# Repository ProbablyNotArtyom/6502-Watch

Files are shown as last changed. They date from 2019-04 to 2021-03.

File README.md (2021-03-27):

# 6502-Watch
6502 powered wearable with an LCD screen, keyboard interface, and compact form factor, all running ehBasic to boot.

<p align="center">
    <a href="https://hackaday.io/project/166496-65p-6502-powered-watch">(Link to this project's Hackaday.io page)</a>
    <br>
    <a href="https://blog.notartyoms-box.net/6502-watch">(Link this project's homepage on my website)</a>
</p>

### About

The 6502 has been around for just about 40 years, yet still powers the hearts of many electrical systems in place today, such as many microcontrollers and embedded systems. In fact, WDC still manufactures the 6502 and 65xx series chips under the 65c02 and 65cxx. I've noticed that WDC also introduced more package variants of the 6502 and 6522, such as PLCC and QFP. Another thing I noticed was the fact that these form factors of the 65c02 are almost never used. Given that the only people buying these are hobbyists, that isn't too suprizing, as they dont offer much over the standard 40 pin DIP.What they do offer, however, is small package size. I went off to try and design the smallest 6502 SBC i could, and was pleasantly suprized with the results. What I ended up with was what i think is the smallest hobbyist 6502 SBC produced. Small enough, in fact, that you could easily wear it on your wrist! I then added the neat little Nokia 5110 LCD and a cool interface, and now have what I believe to be the only 6502-driven watch in existance.

This repository contains all of the KiCad project files for the hardware, and all of the assembly sources for my software. To build the software you will need KickAssembler.

### Hardware

The watch is pretty standard as far as 6502 hardware goes:

 * 65c02 running @ 8MHz
 * 65c22 (controls LCD, keyboard, and buttons)
 * Nokia 5110 LCD (84x48)
 * 32k SRAM
 * 16k ROM
 * C64 Keyboard Connector

Probably the strangest bit there is the full size C64 keyboard connector along the top of the watch. I had wanted to have some form of keyboard input, but most options are entirely out of reach of the poor 6502. The only way i could come up with is to use a preexisting matrix keyboard; I happened to have a lot of unused commodore keyboards, so that's what ended up on there.

The part that ties everything together is really the tiny Nokia LCD. It's interfaced through SPI, which i had to bitbang through the 6522 VIA. The VIA also interfaces with the keyboard, and the face buttons. An interesting thing to note here is that the VIA only has 16 i/o pins, which in this case are all needed to interface just with the keyboard alone. I was able to use some of those pins for both the keyboard and the LCD without causing any sort of corruption with a bit of luck, and a lot more trial and error.

### Software

The watch has a few different things on its ROM. The primary thing is G'Mon, a machine monitor i wrote for the 6502. It  supports viewing memory in single and batch, depositing memory in single or batch, jumping to programs, filling blocks of memory with a pattern byte, and moving blocks of memory. I had to strip a few of the less useful commands out in order to fit it on the ROM with everything else. The secondary thing on there is Lee Davidson's Enhanced Basic. I was just barely able to fit into the ROM with everything else, like there are only around 100 bytes free. EhBasic has been modified to hook into the watch's main code, but other than that it's a completely normal version of EhBasic!

The thing that greets you when you start up the watch is the watch interface. Clever name, i know. It just provides a graphical menu you can move through to select what you want to run. This is the only place where the face buttons are actually used, at least on purpose. The topmost button is what brings up the menu. Interesting bit about that: its connected directly to the NMI pin on the 6502, so it can be used to get back to the watch menu from almost anywhere on the thing (unless you crash the 6502).

In my sources, there is a big blob of code that handles interfacing with the watch hardware; It's called the kernel there, but its less of a kernel and more of a library everything else references. Some of the more interesting things in there are the SPI bitbanging stuff for the LCD, and the matrix scanning and decoding routine for the keyboard.

Speaking of sources, they are all uploaded on here, of course. All the assembler code is written to be assembled using KickAssembler, and makes quite heavy use of its macro capabilities, so i doubt it would be fun to try and assemble with anything else. Here i have also included the EhBasic sources that i have modified; They have been modified to be assembled with KickAssembler. Everything builds at the same time, just run the ./Compile.sh script and it will spit out a ROM image. If for some reason you feel the need to fiddle with it, then make sure to go to Configuration.asm: That's the header that holds a bunch of the miscellaneous variables, like the location of the ROM in memory.

If you every wanted to run the software yourself, then you can do that as well. If you set the Emulated variable in the config file to true, then it will build a ROM for use with Symon.

### Other Software Toys

I have written a few extra programs to show what the hardware itself can do. The first thing is a little sprite demo that has 8 animated software sprites bouncing around the screen, plus a text scroller along the top. The visibility is quite poor with it, as the LCD sure does take its time with updating the pixels, which causes everything moving to be a little blurry. To combat this I had to wait a bit after each frame for the LCD to update, which means that the demo itself runs a little slower than it actually could on the hardware. A video of this demo in action is in the Demos section.

Did i mention it runs Tetris? Because yea, it sure does. I wrote a version of Tetris for the watch not long after realizing it was probably the only practical thing that it could feasibly do. Its a pretty standard Tetris clone, following pretty much all of the mechanics of the original versions. This means having the scoring system, having the progressive levels, all the tetrominoes, etc. Its controlled using the face buttons, using the navigation buttons as left & right, the center button as rotate, and the NMI button as the drop button. At the moment I don't have actual recordings of Tetris running on the watch, mostly because i am too lazy to do that much work for a project that was finished nearly 2 and a half years as of this write-up, but i do have the graphics assets i made for it, and have put them together into what it looks like while. If you don't believe that I wrote Tetris for it, then don't worry, just take a look at the sources that i have included with the project's main downloads.

### More Information

 * [My Website](http://notartyoms-box.net/6502watch.html)

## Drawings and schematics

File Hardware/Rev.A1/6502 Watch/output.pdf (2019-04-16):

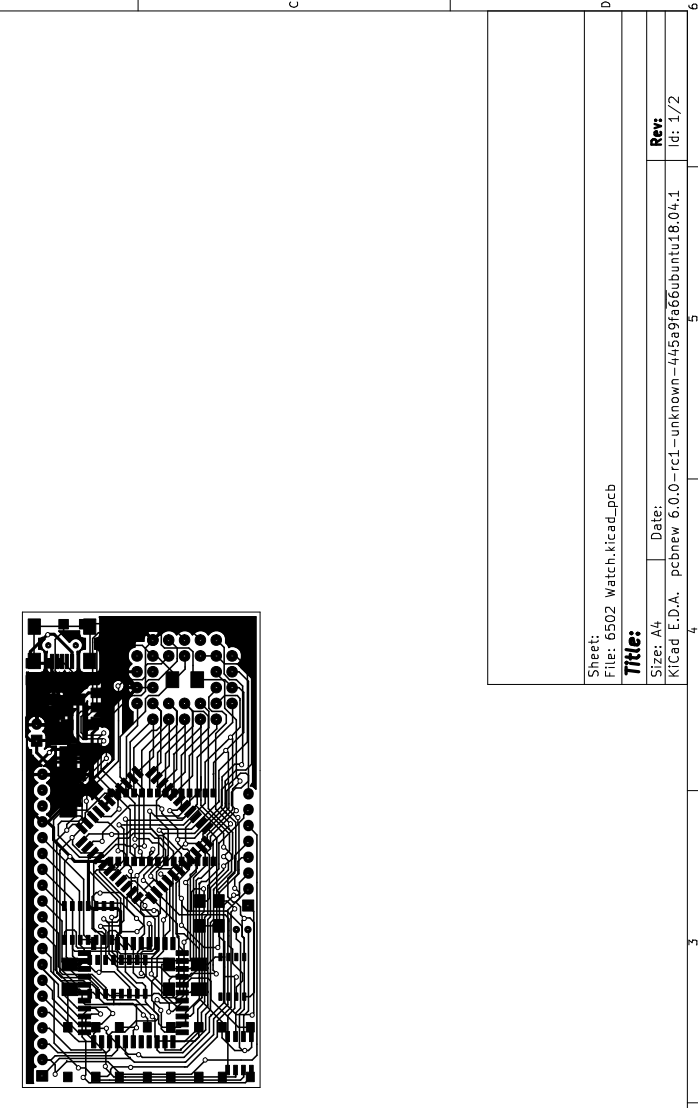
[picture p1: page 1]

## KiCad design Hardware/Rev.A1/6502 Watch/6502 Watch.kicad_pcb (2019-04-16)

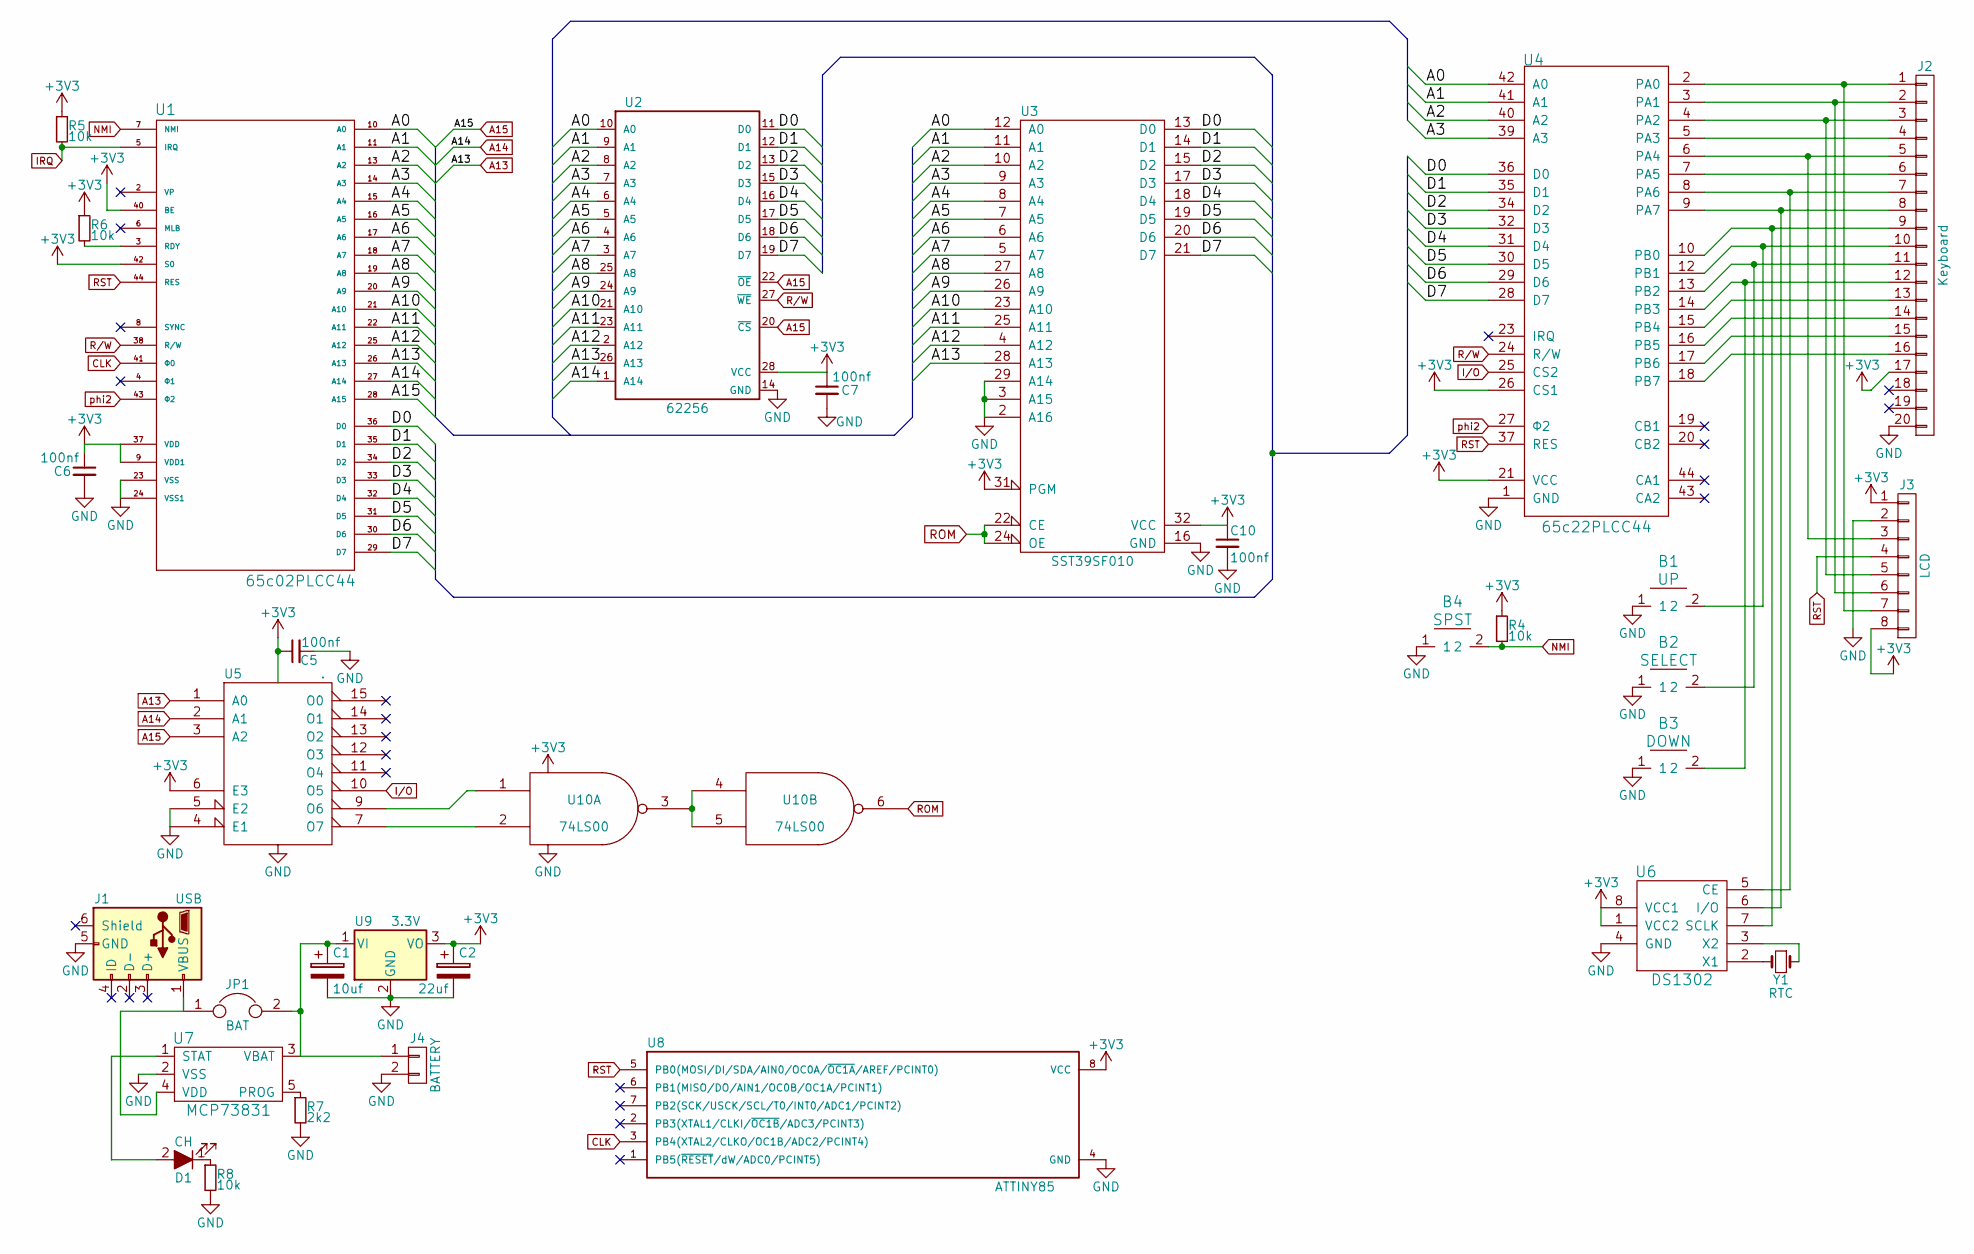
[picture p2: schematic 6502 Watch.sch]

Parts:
B1: UP; SW_SPST_B3S-1000(4P)
B2: SELECT; SW_SPST_B3S-1000(4P)
B3: DOWN; SW_SPST_B3S-1000(4P)
B4: SPST; SW_SPST_B3S-1000(4P)
C1: 10uf; C_1206_HandSoldering
C2: 22uf; C_1206_HandSoldering
C5, C6, C7, C10: 100nf; C_1210_HandSoldering
D1: CH; LED_1206
J1: USB; USB_Mini-B
J2: Keyboard; Pin_Header_Angled_1x20_Pitch2.54mm
J3: LCD; Pin_Header_Straight_1x08_Pitch2.54mm
J4: BATTERY; Pin_Header_Straight_1x02_Pitch2.54mm
JP1: BAT; R_0805_HandSoldering
R4, R5, R6, R8: 10k; R_1206_HandSoldering
R7: 2k2; R_1206_HandSoldering
U1: 65c02PLCC44; PLCC-44
U2: 62256; SOP-28_8.40x48mm_Pitch1.27mm
U3: SST39SF010; PLCC-32_THT-Socket_Fixed
U4: 65c22PLCC44; PLCC-44
U5: .; SOIC-16_3.9x9.9mm_Pitch1.27mm
U6: DS1302; SOIC-8_3.9x4.9mm_Pitch1.27mm
U7: MCP73831; SOT-23-5_HandSoldering
U8: ATTINY85; SOIC-8-N
U9: 3.3V; SOT-223-3Lead_TabPin2
U10: 74LS00; SOIC-14_3.9x8.7mm_Pitch1.27mm
Y1: RTC; Crystal_DS26_d2.0mm_l6.0mm_Horizontal

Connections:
+3V3: C2.1, C5.1, C6.1, C7.1, C10.1, J2.17, J3.1, J3.8, R4.1, R5.1, R6.1, U1.9 (VDD1), U1.37 (VDD), U1.40 (BE), U1.42 (S0), U2.28 (VCC), U3.31 (PGM), U3.32 (VCC), U4.21 (VCC), U4.26 (CS1), U5.6 (E3), U5.16 (VCC), U6.1 (VCC2), U6.8 (VCC1), U8.8 (VCC), U9.3 (VO), U10.14 (VCC)
/A0: U1.10 (A0), U2.10 (A0), U3.12 (A0), U4.42 (A0)
/A1: U1.11 (A1), U2.9 (A1), U3.11 (A1), U4.41 (A1)
/A2: U1.13 (A2), U2.8 (A2), U3.10 (A2), U4.40 (A2)
/A3: U1.14 (A3), U2.7 (A3), U3.9 (A3), U4.39 (A3)
/A4: U1.15 (A4), U2.6 (A4), U3.8 (A4)
/A5: U1.16 (A5), U2.5 (A5), U3.7 (A5)
/A6: U1.17 (A6), U2.4 (A6), U3.6 (A6)
/A7: U1.18 (A7), U2.3 (A7), U3.5 (A7)
/A8: U1.19 (A8), U2.25 (A8), U3.27 (A8)
/A9: U1.20 (A9), U2.24 (A9), U3.26 (A9)
/A10: U1.21 (A10), U2.21 (A10), U3.23 (A10)
/A11: U1.22 (A11), U2.23 (A11), U3.25 (A11)
/A12: U1.25 (A12), U2.2 (A12), U3.4 (A12)
/D0: U1.36 (D0), U2.11 (D0), U3.13 (D0), U4.36 (D0)
/D1: U1.35 (D1), U2.12 (D1), U3.14 (D1), U4.35 (D1)
/D2: U1.34 (D2), U2.13 (D2), U3.15 (D2), U4.34 (D2)
/D3: U1.33 (D3), U2.15 (D3), U3.17 (D3), U4.32 (D3)
/D4: U1.32 (D4), U2.16 (D4), U3.18 (D4), U4.31 (D4)
/D5: U1.31 (D5), U2.17 (D5), U3.19 (D5), U4.30 (D5)
/D6: U1.30 (D6), U2.18 (D6), U3.20 (D6), U4.29 (D6)
/D7: U1.29 (D7), U2.19 (D7), U3.21 (D7), U4.28 (D7)
A13: U1.26 (A13), U2.26 (A13), U3.28 (A13), U5.1 (A0)
A14: U1.27 (A14), U2.1 (A14), U5.2 (A1)
A15: U1.28 (A15), U2.20 (~CS), U2.22 (~OE), U5.3 (A2)
CLK: U1.41 (Φ0), U8.3 (PB4(XTAL2/CLKO/OC1B/ADC2/PCINT4))
GND: B1.1, B2.1, B3.1, B4.1, C1.2, C2.2, C5.2, C6.2, C7.2, C10.2, J1.5 (GND), J2.20, J3.2, J4.2, R7.2, R8.2, U1.23 (VSS), U1.24 (VSS1), U2.14 (GND), U3.2 (A16), U3.3 (A15), U3.16 (GND), U3.29 (A14), U4.1 (GND), U5.4 (E1), U5.5 (E2), U5.8 (GND), U6.4 (GND), U7.2 (VSS), U8.4 (GND), U9.2 (GND), U10.7 (GND)
I/O: U4.25 (CS2), U5.10 (O5)
IRQ: R5.2, U1.5 (IRQ)
NMI: B4.2, B4.4, R4.2, U1.7 (NMI)
unnamed: B1.2, J2.10, U4.12 (PB1)
unnamed: B2.2, J2.11, U4.13 (PB2)
unnamed: B3.2, J2.12, U4.14 (PB3)
unnamed: C1.1, J4.1, JP1.2, U7.3 (VBAT), U9.1 (VI)
unnamed: D1.1 (K), R8.1
unnamed: D1.2 (A), U7.1 (STAT)
unnamed: J1.1 (VBUS), JP1.1, U7.4 (VDD)
unnamed: J2.1, J3.7, U4.2 (PA0)
unnamed: J2.2, J3.6, U4.3 (PA1)
unnamed: J2.3, J3.5, U4.4 (PA2)
unnamed: J2.4, U4.5 (PA3)
unnamed: J2.5, J3.3, U4.6 (PA4)
unnamed: J2.6, U4.7 (PA5)
unnamed: J2.7, U4.8 (PA6), U6.5 (CE)
unnamed: J2.8, U4.9 (PA7), U6.6 (I/O)
unnamed: J2.9, U4.10 (PB0), U6.7 (SCLK)
unnamed: J2.13, U4.15 (PB4)
unnamed: J2.14, U4.16 (PB5)
unnamed: J2.15, U4.17 (PB6)
unnamed: J2.16, U4.18 (PB7)
unnamed: R6.2, U1.3 (RDY)
unnamed: R7.1, U7.5 (PROG)
unnamed: U6.2 (X1), Y1.2
unnamed: U6.3 (X2), Y1.1
unnamed: U5.9 (O6), U10.1
unnamed: U5.7 (O7), U10.2
unnamed: U10.3, U10.4, U10.5
R/W: U1.38 (R/W), U2.27 (~WE), U4.24 (R/W)
ROM: U3.22 (CE), U3.24 (OE), U10.6
RST: J3.4, U1.44 (RES), U4.37 (RES), U8.5 (PB0(MOSI/DI/SDA/AIN0/OC0A/~OC1A~/AREF/P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)
phi2: U1.43 (Φ2), U4.27 (Φ2)

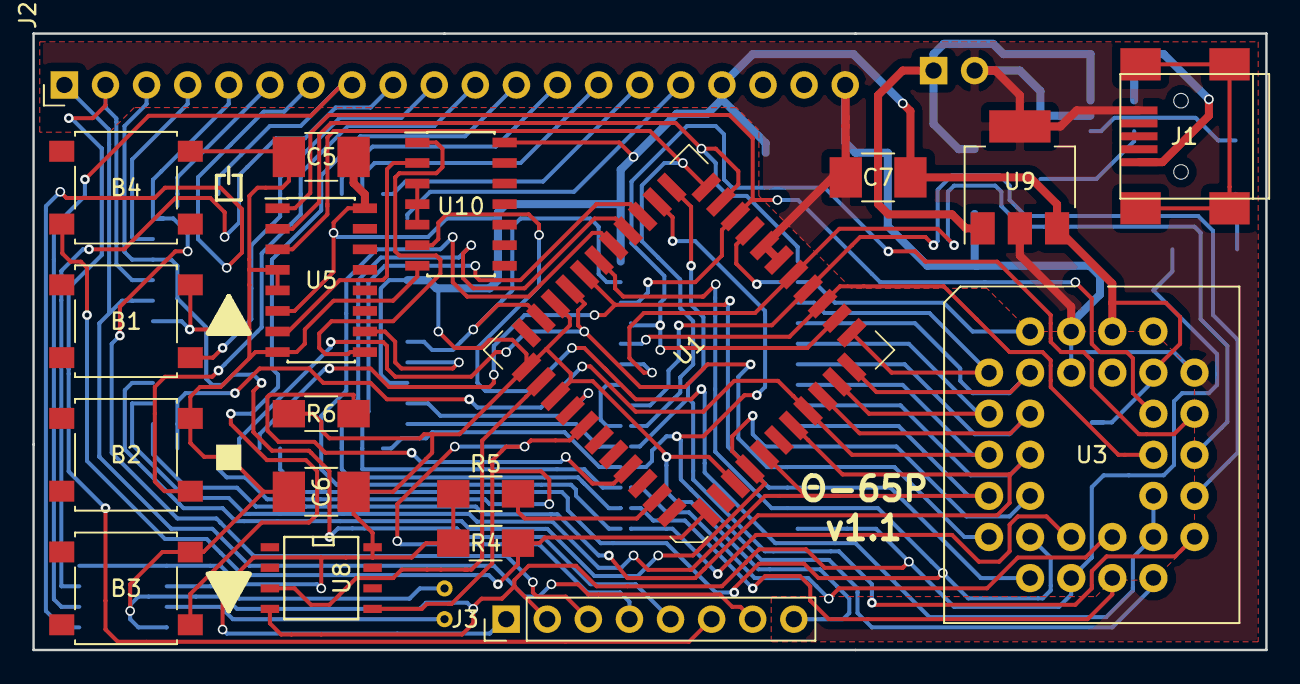
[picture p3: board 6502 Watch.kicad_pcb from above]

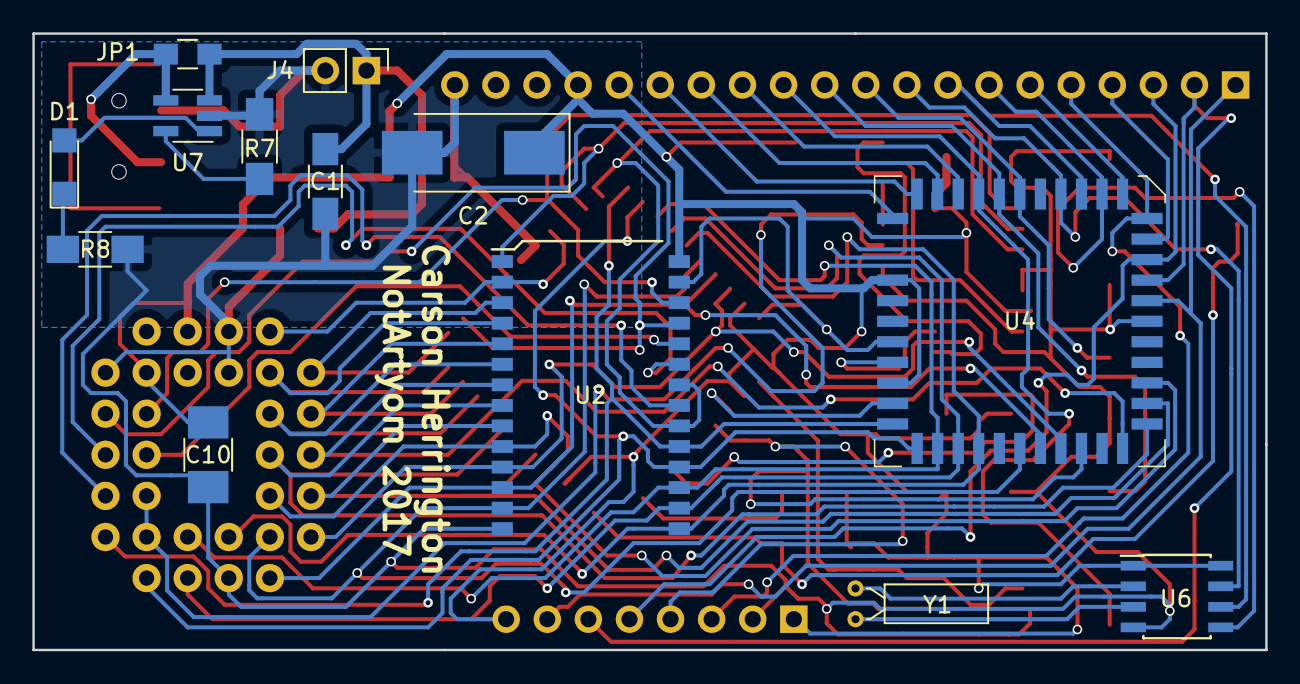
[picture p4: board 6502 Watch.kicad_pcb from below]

Board: 2 copper layers, 76.2 x 38.1 mm, 32 parts (13 on the bottom side), 61 nets.

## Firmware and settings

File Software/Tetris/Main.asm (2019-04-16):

//------------------Origin------------------
				
			*=$C000				// For use with Symon
KStart:
//-----------------Imports------------------	

			#import "Variables.asm"

//------------------Start-------------------	

INIT:							// RAM test, I/O init																																												
			sei					// Disable IRQ
			cld					// Clear decimal flag
			ldx #$FF			// Load X with stack pointer
			txs					// Init stack pointer
			cld
			lda #$00
			sta ADDRS
			sta Score			// Reset game vaiables
			sta ScoreH
			sta ScoreHH
			sta Lines
			lda #$02
			sta ADDRSHI
			jsr RAMInit
			jsr LCDInit
			jsr RNDInit
			lda #$FF
			sta DropLVL
			lda #$0D
			sta BlockID_Next
			
			lda #<Collision		// Write the collision table to memory
			sta GTmp5
			lda #>Collision
			sta GTmp6
			lda #<Table			
			sta GTmp3
			lda #>Table
			sta GTmp4
			ldy #$FF
			ldx #$00
Pct:		iny
			lda (GTmp3),y		// Load a byte of the bitmap
			sta (GTmp5),y
			cpx #$01			// If X != 1
			bne !+
			cpy #$30			// If Y
			bne Pct
			jmp INe			
!:			cpy #$FF			
			bne Pct				
			inc GTmp4			// Increase the High byte of the index		
			inc GTmp6		
			ldx #$01			// Set X == 1 so the second routine can start
			jmp Pct		
INe:
		.if (Emulated){	
			jmp Main	
		}		
			lda #<Title
			sta GTmp3
			lda #>Title
			sta GTmp4
			jsr WriteBMP
			
M0:			lda #$FF
			sta DDRB
			sta PORTB
			lda #$00
			sta DDRB			
			lda PORTB
			ora #%11110001
			cmp #SW_SELECT
			bne M0
Main:			
			lda #<Game
			sta GTmp3
			lda #>Game
			sta GTmp4
			jsr WriteBMP
			
			lda #$01
			sta Level
			
			jsr BlockNew
!:			jsr BDelay
			jsr BlockDown
			jmp !-
					 		
//----------------Functions-----------------	

RAMInit:														
			ldx #$00													
Ra1:		lda	#$00
			sta (ADDRS,x)		// Store byte
						
			lda ADDRS			// Load accumulator with low byte of current test address
			cmp #$FF			// Compare with #$FF to see if it is time to cycle the high byte
			bne !+				// if A =/= #$FF goto end. else continue
			inc ADDRSHI			// Increase current test address high byte
!:			inc ADDRS			// Store #$00 in the low byte				
		
			lda ADDRSHI			// Compare High byte of current address to 80
			cmp #80
			bne Ra1																										
			rts	
			
LCDInit:              
			pha          
			lda DDRA								
			ora #%00011111		// Set the VIA bits to be outputs								
			sta DDRA          
            lda PORTA
            and #%11110110		// Set CLK and RES low
            sta PORTA
            nop					// Delay for a bit
            nop
			lda PORTA
			ora #$00001000		// Set RES high
			sta PORTA
			nop					// Delay a little bit more
			nop
			
			lda #%00100001		// Function set, H == 1
			jsr Command
			lda #%11000111		// Set Contrast
			jsr Command
			lda #%00100000		// Function set, H == 0
			jsr Command
			lda #%00001100		// Set Display Config
			jsr Command
			lda #%10000000		// Set X = 0
			jsr Command
			lda #%01000000		// Set Y = 0
			jsr Command			
			
			jsr LCDClear		// Clear the LCD
			pla
			rts					// Return

LCDHome:
			pha
			jsr LCDClear
			lda #%00100000		// Function set, H == 0
			jsr Command
			lda #%10000000		// Set X = 0
			jsr Command
			lda #%01000000		// Set Y = 0
			jsr Command
			pla
			rts

LCDClear:
			pha
			txa
			pha
			tya
			pha
			ldy #$00
			ldx #$00
			lda #%10000000		// Set X = 0
			jsr Command
			lda #%01000000		// Set Y = 0
			jsr Command
CL1:		lda #$00
			jsr WriteBYTE		// Write the byte
			iny					// Increase the index
			cpx #$01			// Check if we're on the second loop
			beq !+
			cpy #$FF			
			bne CL1					
			ldx #$01			// Set X == 1 so the second routine can start
			jmp CL1				// Jump back to the loop
!:			cpy #$F8			
			bne CL1
			
			pla			
			tay			
			pla			
			tax			
			pla				
			rts			
						
Command:
			sta GTmp			// Save input				
			tya					// Push y to the stack	
			pha																				
			lda DDRA								
			ora #%00011111		// Set the VIA bits to be outputs								
			sta DDRA							
			lda #%00111000		// Set LCD_RS bit to character input mode (High)						
			sta PORTA			// Output it							
!:			lda PORTA
			and #%11101111		// Set the enable bit low
			sta PORTA			// Output it
			ldy #$FF			// Setup Y for the output loop													
!:			lda PORTA			
			and #%11111101		// Set the Data line low to ready it for bit-shifting 
			sta PORTA			// Output it
			lda #$00			// Load A with zero for input
			clc					// Clear Carry
			asl GTmp			// Shift next bit of The input into Carry	
			rol					// Rol the bit into A
			clc					// Clear carry to make sure bit 0 of A == 0
			rol					// Rol A to put the data bit in the correct location
			ora PORTA			// Or it with the output
			sta PORTA			// Output the data bit
			inc	PORTA			// Pulse the Clock to latch the data
			dec	PORTA					
			iny 				// Increase the index
			cpy #$08			// If Y == 8, then all of the bits have been output
			bne !-				// If not, then jmp to output another bit				
!:			
			lda #%00111000
			sta PORTA
			pla								
			tay					// Pull Y from the stack			
			rts					// Return									
												
WriteBYTE: 													
			sta GTmp			// Save input				
			pha		
			tya					// Push y to the stack	
			pha											
			lda DDRA								
			ora #%00011111		// Set the VIA bits to be outputs								
			sta DDRA							
			lda #%00111100		// Set LCD_RS bit to character input mode (High)						
			sta PORTA			// Output it							
!:			lda PORTA
			and #%11101111		// Set the enable bit low
			sta PORTA			// Output it
			ldy #$FF			// Setup Y for the output loop													
!:			lda PORTA			
			and #%11111101		// Set the Data line low to ready it for bit-shifting 
			sta PORTA			// Output it
			lda #$00			// Load A with zero for input
			clc					// Clear Carry
			asl GTmp			// Shift next bit of The input into Carry	
			rol					// Rol the bit into A
			clc					// Clear carry to make sure bit 0 of A == 0
			rol					// Rol A to put the data bit in the correct location
			ora PORTA			// Or it with the output
			sta PORTA			// Output the data bit
			inc	PORTA			// Pulse the Clock to latch the data
			dec	PORTA					
			iny 				// Increase the index
			cpy #$08			// If Y == 8, then all of the bits have been output
			bne !-				// If not, then jmp to output another bit				
!:			
			lda #%00111000
			sta PORTA
			pla								
			tay					// Pull Y from the stack			
			pla		
			rts					// Return									
												
WriteBMP:						// Writes a bitmap to the screen. GTmp3(L) and GTmp4(H) must contain a pointer to the bitmap
			pha
			txa
			pha
			tya
			pha
			jsr LCDHome
			lda #<Screen
			sta GTmp5
			lda #>Screen
			sta GTmp6
			ldy #$FF
			ldx #$00
WB1:		iny
			lda (GTmp3),y		// Load a byte of the bitmap
			sta (GTmp5),y
			jsr WriteBYTE		// Write the byte
			cpx #$01			// If X != 1
			bne !+
			cpy #$F8			// If Y
			bne WB1
			pla			
			tay			
			pla			
			tax			
			pla				
			rts
			
!:			cpy #$FF			
			bne WB1				
			inc GTmp4			// Increase the High byte of the index		
			inc GTmp6		
			ldx #$01			// Set X == 1 so the second routine can start
			jmp WB1				// Jump back to the loop								
												
SETCursor:
			pha
			lda LCDX								
			ora #%10000000								
			jsr Command								
			lda LCDY					
			asl					
			asl					
			asl					
			ora #%01000000								
			jsr Command							
			pla							
			rts							
										
SETCursor_3b:
			pha
			lda LCDX								
			ora #%10000000								
			jsr Command								
			lda LCDY									
			ora #%01000000								
			jsr Command							
			pla							
			rts							
												
BDelay:							// Dealy for a lot of cycles
			txa
			pha
			tya 
			pha
			
			ldx DropDelay		// Load X with #$FF
RS:			ldy #$FF			// Load Y with #$FF
!:			dey					// Decrease Y (Sub loop)
		.if (Emulated){
			rol $10
		}else{
			rol $10
			ror $10
			rol $10
			ror $10
			rol $10
			ror $10
			rol $10
			ror $10
			rol $10
			ror $10
			rol $10
			ror $10
		}
			cpy #$00			// Compare it to 0
			bne !-				// If Y =/= 0, loop again
			jsr Input
			dex					// After one full loop of Y, Decrease X by one
			cpx #$00			// Compare X to 0
			bne RS				// If X =/= 0, loop Y once more			
			pla 
			tay
			pla
			tax
			rts												

Input:		
			pha
			txa
			pha
!:			lda #$FF
			sta DDRB
			sta PORTB
			lda #$00
			sta DDRB			
			lda PORTB
			ora #%11110001
			cmp #$FF
			beq !+
			cmp lastkey
			bne !+
			jmp IOe
!:			sta lastkey
			cmp #SW_SELECT
			bne !+
			jsr BlockRotate
			jmp IOe
			
!:			cmp #SW_LEFT
			bne !+
			jsr BlockLeft
			jmp IOe
			
!:			cmp #SW_RIGHT
			bne !+
			jsr BlockRight
			jmp IOe
IOe:			
!:			pla
			tax
			pla
			rts

//-------------Game Functions---------------					

GameEnd:
			jmp INIT
CHLines:
			lda Lines
			cmp #$0A
			bne !+
			inc Level		
			lda #$00		
			sta Lines		
!:			rts

CHLevel:
			ldy Level
			lda LDTbl,y
			sta DropLVL
			rts
			
PRScore:						
			pha				
			tya				
			pha				

			lda #$05								
			sta TLength								
			lda #<Tiles+150
			sta B0Tiles
			lda #$F7							
			sta B0TilesH										
			lda #13
			sta LCDX										
													
			lda ScoreHH			
			and #%00001111			
			tay			
			lda NTblL,y
			sta BTiles
			lda NTblH,y
			sta BTilesH		
			lda #12
			sta LCDY	
			jsr PBlock_CL											
													
			lda ScoreH				
			and #%11110000				
			lsr				
			lsr				
			lsr				
			lsr				
			tay
			lda NTblL,y
			sta BTiles
			lda NTblH,y
			sta BTilesH
			lda #08
			sta LCDY
			jsr PBlock_CL			
			lda ScoreH			
			and #%00001111			
			tay			
			lda NTblL,y
			sta BTiles
			lda NTblH,y
			sta BTilesH		
			lda #12
			sta LCDY	
			jsr PBlock_CL			
						
			lda Score				
			and #%11110000				
			lsr				
			lsr				
			lsr				
			lsr				
			tay
			lda NTblL,y
			sta BTiles
			lda NTblH,y
			sta BTilesH
			lda #16
			sta LCDY
			jsr PBlock_CL			
			lda Score		
			and #%00001111			
			tay			
			lda NTblL,y
			sta BTiles
			lda NTblH,y
			sta BTilesH		
			lda #20
			sta LCDY
			jsr PBlock_CL			
	
			pla				
			tay				
			pla				
			rts				
									
PRLevel:
			pha				
			tya				
			pha				

			lda #$05								
			sta TLength								
			lda #<Tiles+150
			sta B0Tiles
			lda #$F7							
			sta B0TilesH										
			lda #01
			sta LCDX													
						
			lda Level				
			and #%11110000				
			lsr				
			lsr				
			lsr				
			lsr				
			tay
			lda NTblL,y
			sta BTiles
			lda NTblH,y
			sta BTilesH
			lda #16
			sta LCDY
			jsr PBlock_CL			
			lda Level		
			and #%00001111			
			tay			
			lda NTblL,y
			sta BTiles
			lda NTblH,y
			sta BTilesH		
			lda #20
			sta LCDY
			jsr PBlock_CL			
	
			pla				
			tay				
			pla				
			rts		
			
BlockSlam:
			pha
			lda #$01
			sta DropDelay
			pla
			rti 
			
BlockErase:						// Erases a tetromino		
			pha			
			tya			
			pha			
			txa			
			pha			
									
			ldy BlockID
			lda TTblL,y			// Get the low byte of the block's graphics pointer
			sta BTiles
			lda TTblH,y			// Get the high byte of the block's graphics pointer
			sta BTilesH
			lda TETblL,y		// Get the low byte of the block's graphics pointer
			sta B0Tiles
			lda TETblH,y		// Get the high byte of the block's graphics pointer
			sta B0TilesH			
						
			ldy BlockX
			lda BSTblX,y		// Use the Block X position to find the Y screen position of the block
			sta LCDY
			ldy BlockY
			lda BSTblY,y		// Use the Block Y position to find the X screen position of the block
			sta LCDX
			jsr EBlock		
						
			pla			
			tax			
			pla			
			tay			
			pla			
			rts			
						
BlockPrint:						// Prints a block at the current (BlockX, BlockY) position			
			pha			
			tya			
			pha			
			txa			
			pha			
						
			ldy BlockID
			lda TTblL,y			// Get the low byte of the block's graphics pointer
			sta BTiles
			lda TTblH,y			// Get the high byte of the block's graphics pointer
			sta BTilesH
			lda TETblL,y		// Get the low byte of the block's graphics pointer
			sta B0Tiles
			lda TETblH,y		// Get the high byte of the block's graphics pointer
			sta B0TilesH			
						
			ldy BlockX
			lda BSTblX,y		// Use the Block X position to find the Y screen position of the block
			sta LCDY
			ldy BlockY
			lda BSTblY,y		// Use the Block Y position to find the X screen position of the block
			sta LCDX
			jsr PBlock	
			
			pla			
			tax			
			pla			
			tay			
			pla			
			rts			
							
BlockRight:						// Moves the tetromino right one space
			jsr ECData
			inc BlockX
			jsr CCData
			bcs !+
			dec BlockX
			jsr BlockErase
			inc BlockX
			jsr PCData
			jsr BlockPrint
			rts
!:			dec BlockX
			jsr PCData
			rts					

BlockLeft:						// Moves the tetromino left one space
			jsr ECData
			dec BlockX
			jsr CCData
			bcs !+
			inc BlockX
			jsr BlockErase
			dec BlockX
			jsr PCData
			jsr BlockPrint
			rts
!:			inc BlockX
			jsr PCData
			rts

BlockDown:						// Moves the tetromino down one space
			pha					
			jsr ECData		
			dec BlockY
			jsr CCData
			bcs !+
			inc BlockY
			jsr BlockErase
			dec BlockY
			jsr PCData
			jsr BlockPrint
			pla
			rts			
!:			inc BlockY
			jsr PCData
			jsr BlockNew
			pla
			rts
			
BlockRotate:					// Rotates a block CW
			pha
			tya
			pha
			
			jsr ECData
			ldy BlockID
			lda RTbl,y			// Lookup how many rotations are left in this blocks cycle
			cmp #$00
			bne R0				// If there are still cycles left, then branch to continue
			lda BlockID
			pha
			lda BlockID_B
			sta BlockID
			jsr CCData
			bcs !+
			pla
			sta BlockID
			jsr BlockErase
			lda BlockID_B
			sta BlockID
			jsr PCData
			jsr BlockPrint
			jmp Re
!:			pla
			sta BlockID
			jsr PCData
			jmp Re				// Exit the routine
R0:			inc BlockID
			jsr CCData
			bcs !+
			dec BlockID
			jsr BlockErase
			inc BlockID
			jsr PCData
			jsr BlockPrint
			jmp Re
!:			dec BlockID
			jsr PCData
			jmp Re
			
Re:			pla
			tay
			pla
			rts

BlockNew:						// Creates a new tetromino and sets up it's graphics data
			pha
			tya
			pha
			
			jsr CLine			// Check if any lines have been formed
			
			lda #%10000000		// Set X = 0
			jsr Command
			lda #%01000000		// Set Y = 0
			jsr Command
			lda #$03
			jsr WriteBYTE
			
			lda BlockID_Next
			pha
			jsr IDGen
			tay
			lda BTbl,y			// Use the random number as an index to get the next blockID
			sta BlockID_Next
			pla
			sta BlockID
			sta BlockID_B
			lda #07
			sta LCDX
			lda #31
			sta LCDY
			
			ldy BlockID
			lda TTblL,y			// Get the low byte of the block's graphics pointer
			sta BTiles
			lda TTblH,y			// Get the high byte of the block's graphics pointer
			sta BTilesH
			lda TETblL,y		// Get the low byte of the block's graphics pointer
			sta B0Tiles
			lda TETblH,y		// Get the high byte of the block's graphics pointer
			sta B0TilesH
			
			jsr PBlock
			jsr EBlock			// Erase the last thing that was in the "Next Piece" display
			
			ldy BlockID_Next	// Print the next tetromino
			sty BlockID
			lda TTblL,y			// Get the low byte of the block's graphics pointer
			sta BTiles
			lda TTblH,y			// Get the high byte of the block's graphics pointer
			sta BTilesH
			lda TETblL,y		// Get the low byte of the block's graphics pointer
			sta B0Tiles
			lda TETblH,y		// Get the high byte of the block's graphics pointer
			sta B0TilesH
			
			lda #07
			sta LCDX
			lda #31
			sta LCDY
			jsr PBlock			// Print the next piece in the "Next Piece" display
			
			ldy BlockID_B
			sty BlockID
			
			lda #4
			sta BlockX
			lda #16
			sta BlockY
			lda #75
			sta LCDX
			lda #17
			sta LCDY
			
			jsr CCData
			bcc !+				
			jmp GameEnd			// Unable to print another tetromino, end the game
!:			jsr PCData
			jsr BlockPrint
			
			lda DropLVL
			sta DropDelay
			
			pla
			tay
			pla
			rts
RNDInit:
			ldx #$89
			stx IDSeed
			dex
			stx IDSeed+1
			rts

IDGen:							// Generates a "random" Block ID
			lda IDSeed 		
			and #%00000111
			cmp #$07
			bne !+
			jsr NEWSeed
			jmp IDGen
!:			pha
			jsr NEWSeed
			pla
			rts

NEWSeed:
			lda IDSeed
			and #%00000010
			sta TMPSeed
			lda IDSeed+1
			and #%00000010
			eor TMPSeed
			clc
			beq !+
			sec
!:			ror IDSeed
			ror IDSeed+1
			rts

PBlock_CL:	
			lda LCDX		
			pha		
			lda LCDY		
			pha
			jmp PBep
PBlock:		
			lda LCDX		
			pha		
			lda LCDY		
			pha		
	
			lda #$09			// For normal blocks, the tile length is 9 bytes
			ldy BlockID
			cpy #$11			// If the BlockID is == 11, (Iu), then the tile length is extended to 12 bytes
			bne !+
			lda #$0C
!:			sta TLength
PBep:
			jsr SETCursor

			lda LCDY
			lsr
			lsr
			lsr
			pha
			tay					// Divide by 8
			
			lda PTblL,y			// Set up the screen vector	GTmp2
			sta VScreen		
			lda PTblH,y		
			sta VScreenH	
			iny	
			lda PTblL,y			// Set up the screen vector	GTmp9
			sta V0Screen		
			lda PTblH,y		
			sta V0ScreenH
			iny	
			lda PTblL,y			// Set up the screen vector	GTmp9
			sta V1Screen		
			lda PTblH,y		
			sta V1ScreenH
								
			ldy LCDY					
			pla
			sta LCDY
			lda PTbl1,y					
			sta GTmp6			// Grab the number of ASLs needed to get the character to the input position					
			pha			
						
			ldy #$00					
			sty GTmp5					

P1:			lda #$00
			sta GTmp3
			ldy GTmp5
			lda (B0Tiles),y			
			sta GTmp2					
			cpy TLength
			beq P3		
			lda (BTiles),y			// Write 6 consecutive bytes (1 5x8 character) from the address to the screen GTmp7
!:			ldx GTmp6
			cpx #$00
			beq !+
			asl
			rol GTmp2
			rol GTmp3
			dec GTmp6
			jmp !-
			
!:			jsr SETCursor_3b
			ldy LCDX
			ora (VScreen),y			
			sta (VScreen),y			
			jsr WriteBYTE		
			inc LCDY		
			jsr SETCursor_3b		// Set the cursor to the byte below the main one		
			lda GTmp2
			ora (V0Screen),y
			sta (V0Screen),y
			jsr WriteBYTE
			inc LCDY		
			jsr SETCursor_3b		// Set the cursor to the byte below the main one		
			lda GTmp3
			ora (V1Screen),y
			sta (V1Screen),y
			jsr WriteBYTE
			dec LCDY
			dec LCDY
			jsr SETCursor_3b
			inc GTmp5			
			inc LCDX			
			pla	
			pha
			sta GTmp6	
			jmp P1	
P3:			pla			
			pla		
			sta LCDY		
			pla 		
			sta LCDX				
			rts			

EBlock:		
			lda LCDX		
			pha		
			lda LCDY		
			pha		
	
			lda #$09			// For normal blocks, the tile length is 9 bytes
			ldy BlockID
			cpy #$11			// If the BlockID is == 11, (Iu), then the tile length is extended to 12 bytes
			bne !+
			lda #$0C
!:			sta TLength

			jsr SETCursor

			lda LCDY
			lsr
			lsr
			lsr
			pha
			tay					// Divide by 8
			
			lda PTblL,y			// Set up the screen vector	GTmp2
			sta VScreen		
			lda PTblH,y		
			sta VScreenH	
			iny	
			lda PTblL,y			// Set up the screen vector	GTmp9
			sta V0Screen		
			lda PTblH,y		
			sta V0ScreenH
			iny	
			lda PTblL,y			// Set up the screen vector	GTmp9
			sta V1Screen		
			lda PTblH,y		
			sta V1ScreenH
								
			ldy LCDY					
			pla
			sta LCDY
			lda PTbl1,y					
			sta GTmp6			// Grab the number of ASLs needed to get the character to the input position					
			pha			
						
			ldy #$00					
			sty GTmp5					

E1:			lda #$00
			sta GTmp3
			ldy GTmp5
			lda (B0Tiles),y			
			sta GTmp2					
			cpy TLength
			beq E3		
			lda (BTiles),y			// Write 6 consecutive bytes (1 5x8 character) from the address to the screen GTmp7
!:			ldx GTmp6
			cpx #$00
			beq !+
			asl
			rol GTmp2
			rol GTmp3
			dec GTmp6
			jmp !-

!:			jsr SETCursor_3b
			ldy LCDX
			eor (VScreen),y			
			sta (VScreen),y			
			jsr WriteBYTE		
			inc LCDY		
			jsr SETCursor_3b		// Set the cursor to the byte below the main one		
			lda GTmp2
			eor (V0Screen),y
			sta (V0Screen),y
			jsr WriteBYTE
			inc LCDY
			jsr SETCursor_3b
			lda GTmp3
			eor (V1Screen),y			
			sta (V1Screen),y			
			jsr WriteBYTE		
			dec LCDY
			dec LCDY
			jsr SETCursor_3b
			inc GTmp5			
			inc LCDX			
			pla	
			pha
			sta GTmp6	
			jmp E1	
E3:			pla			
			pla		
			sta LCDY		
			pla 		
			sta LCDX				
			rts								
									
CCData:								// Checks if a block can be moved to a position without collision // C = 1 (collision) c = 0 (Safe)					
			pha
			tya
			pha
					
			lda #$01
			sta GTmp4
			sta GTmp5
			lda BlockX
			sta GTmp6
		
			ldy BlockID
			lda CTblL,y
			sta CTiles
			lda CTblH,y
			sta CTilesH
			
			ldy BlockY
			iny
			iny
			sty GTmp3
CC0:		ldx BlockX
			lda CSTblL,y			
			sta CScreen			
			lda CSTblH,y			
			sta CScreenH			
			ldy #$00					
			sty GTmp7				
!:			ldy GTmp7
			lda (CTiles),y						
			cmp #$20						
			beq CC1
			
			ldy GTmp6
			lda (CScreen),y
			cmp #$20
			bne	CCe
			ldy GTmp7
			lda (CTiles),y
			
CC1:		inc GTmp7
			inc GTmp6
			lda GTmp5
			inc GTmp5
			cmp #$03
			bne !-
			lda #$01
			sta GTmp5
			lda GTmp4
			inc GTmp4
			cmp #$03
			beq CCe0
			dec GTmp3
			ldx GTmp3
			lda CSTblL,x			
			sta CScreen			
			lda CSTblH,x			
			sta CScreenH
			lda BlockX
			sta GTmp6
			jmp !-		
			
CCe0:		clc
			jmp !+
CCe:		sec			
!:			pla
			tay
			pla
			rts
			
PCData:								// Checks if a block can be moved to a position without collision // C = 1 (collision) c = 0 (Safe)					
			pha
			tya
			pha
			
			lda #$01
			sta GTmp4
			sta GTmp5
			lda BlockX
			sta GTmp6
			
			ldy BlockID
			lda CTblL,y
			sta CTiles
			lda CTblH,y
			sta CTilesH

			ldy BlockY
			iny
			iny
			sty GTmp3
PC0:		ldx BlockX
			lda CSTblL,y			
			sta CScreen			
			lda CSTblH,y			
			sta CScreenH			
			ldy #$00					
			sty GTmp7				
!:			ldy GTmp7
			lda (CTiles),y						
			cmp #$20						
			beq PC1
			ldy GTmp6
			sta (CScreen),y
			
PC1:		inc GTmp7
			inc GTmp6
			lda GTmp5
			inc GTmp5
			cmp #$03
			bne !-
			lda #$01
			sta GTmp5
			lda GTmp4
			inc GTmp4
			cmp #$03
			beq PCe0
			dec GTmp3
			ldx GTmp3
			lda CSTblL,x			
			sta CScreen			
			lda CSTblH,x			
			sta CScreenH
			lda BlockX
			sta GTmp6
			jmp !-		
			
PCe0:		pla
			tay
			pla
			rts
		
ECData:								// Checks if a block can be moved to a position without collision // C = 1 (collision) c = 0 (Safe)					
			pha
			tya
			pha
			
			lda #$01
			sta GTmp4
			sta GTmp5
			lda BlockX
			sta GTmp6

			ldy BlockID
			lda CTblL,y
			sta CTiles
			lda CTblH,y
			sta CTilesH

			ldy BlockY
			iny
			iny
			sty GTmp3
EC0:		ldx BlockX
			lda CSTblL,y			
			sta CScreen			
			lda CSTblH,y			
			sta CScreenH			
			ldy #$00					
			sty GTmp7				
!:			ldy GTmp7
			lda (CTiles),y						
			cmp #$20						
			beq EC1
			lda #$20
			ldy GTmp6
			sta (CScreen),y
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

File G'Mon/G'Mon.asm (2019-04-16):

Start_OS:	
			sei
			jsr LCDHome
			.if (BootMessage) jmp MonitorBoot 
			jmp Main

		.var CMDNumber	= $07		// Number of commands 
			
//------------Monitor Functions--------------		
												
KEYin:								// Waits for a key input
		.if (Emulated) {
!:			lda ACIA1sta          
			and #$08
			beq !-
			lda ACIA1dat   
			rts                    
		} else {
			lda #$60
			jsr Delay
			jsr GETKey
			cmp #$FF
			beq KEYin
			rts
		}
BRKChk:								// Checks for a break condition (Run/Stop Key)
			pha
        .if (Emulated) {
            pla            
            rts
        } else {
			jsr GETKey
			cmp #$04
			beq !+
			pla
			rts
!:			jmp Main
        }

PRWord:        						// Prints word AAXX   
			jsr PRByte				
			txa
PRByte:		pha						// Prints byte AA	
			lsr						
			lsr						
			lsr						
			lsr						
			jsr PRHex						
			pla					
PRHex:		and #%00001111			// Prints digit A
			tay
			lda HEX,y				
			jmp Write				
															
//-----------------Monitor-------------------	

MonitorBoot:      
			lda #$00
			jsr SETCursor  
			ldx #$00
!:			lda Porttxt,x
			cmp #$00
			beq Main
			jsr Write
			inx			
			jmp !-  			  
Main:		
			jsr BFlush
			ldx #$FF
			txs
Input:		ldy #$00				// Set Y to zero to start tracking input length
			sty Parse
			jsr CReturn
			lda #MONPrompt
			jsr Write
			jsr BFlush				// Empty the input buffer
Input1:		jsr KEYin				// Input the current key
			
		.if (Emulated){
			cmp #$7B
			bcs !+
			cmp #$61
			bcc !+
			and #%11011111
!:			
			cmp #$1B 				// Escape (Emulator)
		} else {  
			cmp #$03			  	// F1 (F1)
		}
			bne !+           
			jsr LCDHome
            jmp BAS

!:          cmp #$0D				// Is it an enter (Carridge Return)?
			beq Input4				// If yes, then we are done inputing text
			cmp #$08				// If not, then check if it is a backspace			
			beq Input3				// If it is, then skip to the backspace routine			
Input2:		cpy #$FF				// Is the input length about to be a full page long?
			bne !+					// If not, then continue to input characters
			jmp Input4				// If so, then exit the input routine		
!:			sta Buffer,y			// Store the input in the buffer
			jsr Write
			iny						// Increase the character pointer
			jmp Input1				// Input another character
			
Input3:		cpy #$00        	      
            beq Input1	        	// If there are no characters in the buffer, then skip the backspace routine
            lda #$00
            sta Buffer,y
            dey                  	// Purge the last input character
            
            ldx LCDCursor
            dex
            txa
            jsr SETCursor
            lda #$20
            jsr Write
            ldx LCDCursor
            dex
            txa
            jsr SETCursor
            
            jmp Input1
Input4:		lda #$0D	
			sta Buffer,y	
Main1:																						
			ldy #$FF				// Reset X for indexed addressing in the loop
			
Main2:		
			iny
Main3:		lda	Buffer,y			// Grab a character from the input buffer
			cpy #$FF
			beq Main1
			ldx #$FF					
!:			inx						// Increase index for the command finder loop
			cpx #CMDNumber			// Has the loop already compared the input to all of the avalible digits?
			beq !+					// If so, then the hex input is over
			cmp	CMD,x				// Compare it to the avalible commands
			bne !-
			jmp Main5
!:			ldx #$FF
!:			inx
			cpx #16
			beq Main2
			cmp HEX,x
			bne !-
			
			lda #$00
			sta WORDInput
			sta WORDInput_H
			dey
MNT:		iny
			lda Buffer,y
			ldx #$FF
!:			inx						// Increase index for the command finder loop
			cpx #$10				// Has the loop already compared the input to all of the avalible digits?
			beq Main3				// If so, then the hex input is over
			cmp	HEX,x				// Compare it to the avalible commands
			bne !-
			
			txa				
			ldx #$04
!:			asl WORDInput	
			rol WORDInput_H	
			dex	
			bne !-	
			ora WORDInput	
			sta WORDInput			
			jmp MNT												
Main4:													
Main5:		sty Parse
			txa
			asl
			tax								
			lda #>Main7				// Push high byte of return address		
			pha			
			lda #<Main7-1			// Push low byte of return address	
			pha			
Main6:          				  	// RTS into the command by pushing the address of the code into the stack
            lda JCMD,x
            sta GTmp 
            inx
            lda JCMD,x
            pha
            lda GTmp 
            pha
            rts           
Main7:
			jmp Input
BFlush:
			ldx #$FF
			lda #$00
!:			inx
			sta Buffer,x
			cpx #$FF
			bne !-
			rts

//-------------Monitor Funtions--------------

View:		
			jsr CReturn				// Call a Carridge Return
			lda WORDInput_H			// Load the high byte of the input into A
			ldx WORDInput			// Load the low byte of the input into A
			jsr PRWord				// Print the full word
			lda #$20				
			jsr Write				// Write a space
			lda #'-'
			jsr Write				// Write a dash
V0:			lda #$20
			jsr Write				// Write a space
			ldx #$00
			lda (WORDInput,x)		// Load the Data from the input position
			jsr PRByte				// Print the byte
			jsr IAddr				// Increase the address pointer
			jsr BRKChk				// Check for break
			rts						// Return from the loop
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
